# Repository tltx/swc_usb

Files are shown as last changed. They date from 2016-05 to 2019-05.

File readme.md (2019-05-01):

SWC USB Adapter
===============
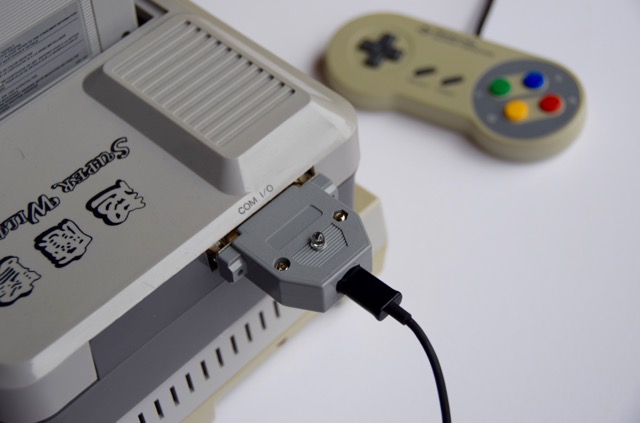
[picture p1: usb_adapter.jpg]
SWC USB Adapter


SWC USB Adapter is a peripheral for the Super Wild Card backup unit that makes it USB compatible.

Features
--------
* Connect a Super Wild Card via USB to a modern computer that does not have a parallel port.
* Compatible with most operating systems. The program is writen in Python and the adapter uses the USB CDC driver that is built into most modern operating systems.
* Transfer speed on par with parallel port transfer.
* No need for a thick parallel port cable.
* More convenient than floppies or a USB floppy emulator.
* The hardware parts are widely available and not too hard to assemble.
* Program auto detects the adapter, no need to specify the port.
* It is a open hardware and software project.

Usage example
-------------

To transfer a ROM file to the Super Wild Card:

`swc_usb.py send-rom --hirom <file>`

To fetch a SRAM dump:

`swc_usb.py fetch-sram <file>`

Questions and answers
----------------------
Q: Why not just use any USB to parallel adapter?

A: It won't work, almost all of them are for printers only, and if you find one that truly emulates a parallel port the latency of USB will make the transfers really slow.

Q: Do I need to surface mount solder and have a PCB manufactured?

A: You should be able to use any Atmega32u4 breakout board and solder wires from it to a male D-Sub 25 connector. That project hardware is basically the same thing but in a nicer form factor.

Q: How do I compile the firmware?

A: swc_usb.hex is a compiled firmware ready to be loaded onto the controller. If you want to compile it yourself, set up a AVR tool chain and run `make all` in the firmware directory.

Q: Does it have all the swc transfer features that Ucon64 has?

A: No, It can send ROM files, send SRAM, fetch SRAM. If there is interest in some other feature I might add it.

Q: Which variants of the Super Wild Card is supported?

A: I think it works on all but I have tested it on: Super Magicom (MS-3201), Super Wild Card (SMS3201), Super Wild Card DX (SWC3201)

Atmega32u4 pin mapping to the D-Sub
-----------------------------------

| Atmega32u4 | D-Sub |
|---|---|
| PB3 | 15 |
| PB4 | 13 |
| PB5 | 12 |
| PB6 | 10 |
| PB7 | 11 |
| PD0 | 2 |
| PD1 | 3 |
| PD2 | 4 |
| PD3 | 5 |
| PD4 | 6 |
| PD5 | 7 |
| PD6 | 8 |
| PD7 | 9 |
| PF4 | 1 |
| PF5 | 14 |
| PF6 | 16 |
| PF7 | 17 |
| GND | 25 |

Thanks
------
This project would probably not have been made without the awesome [LUFA](http://www.fourwalledcubicle.com/LUFA.php) library. [Ucon64](http://ucon64.sourceforge.net/) have been a great source of information on how to communicate with the SWC and a starting point for code.

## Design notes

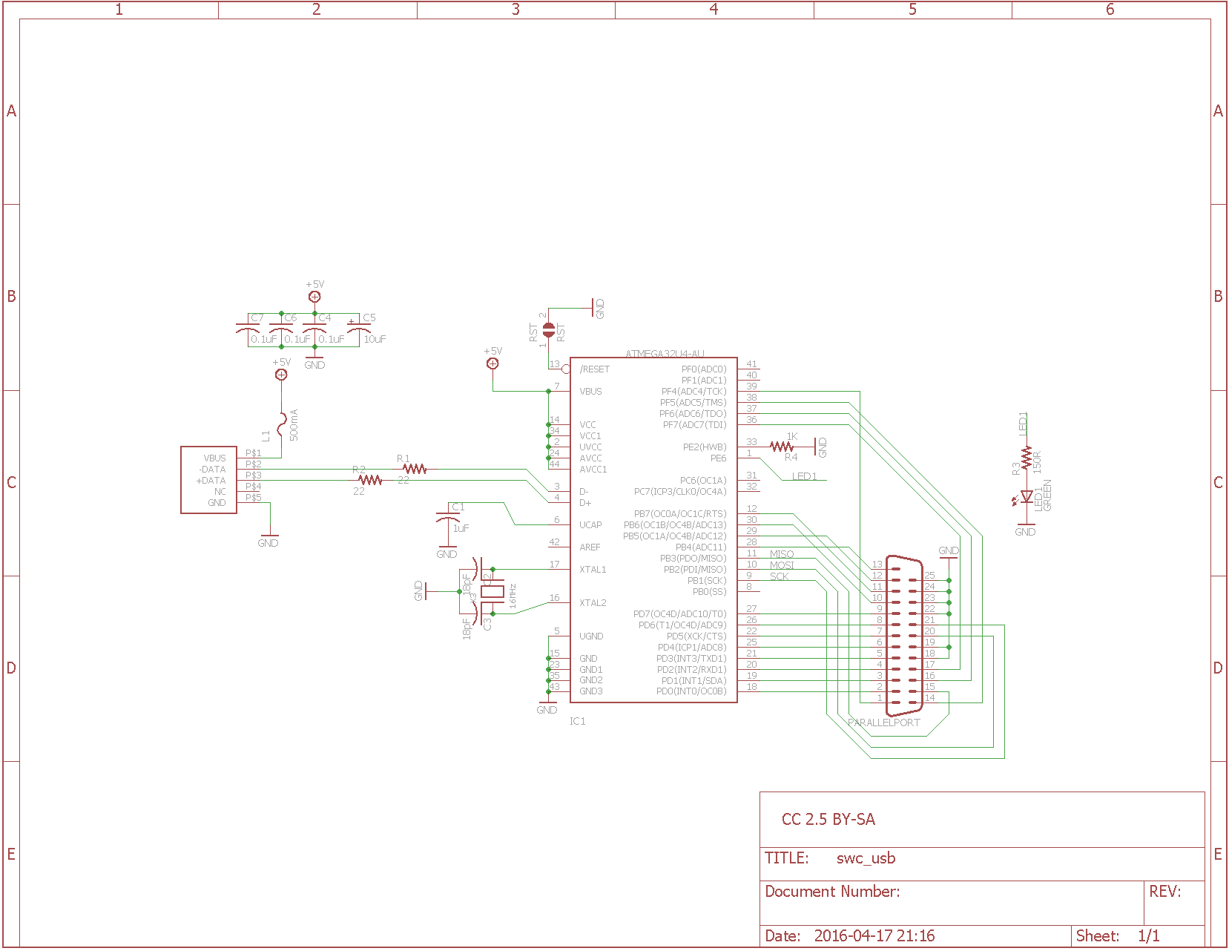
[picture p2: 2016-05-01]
pcb/swc_usb_schematic.png

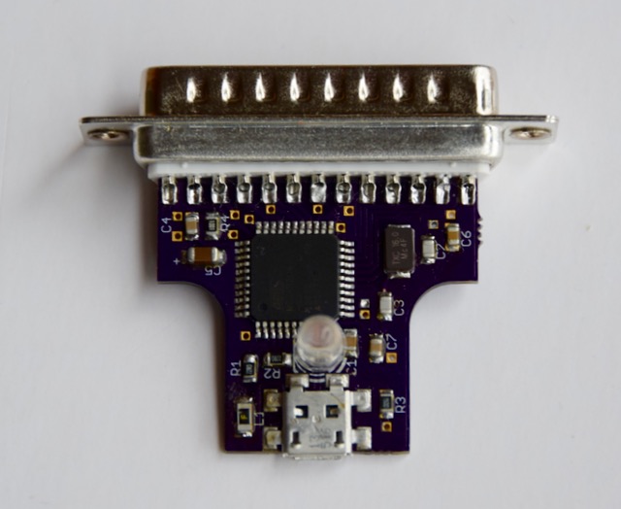
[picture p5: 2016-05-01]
pcb/usb_adapter_pcb.jpg

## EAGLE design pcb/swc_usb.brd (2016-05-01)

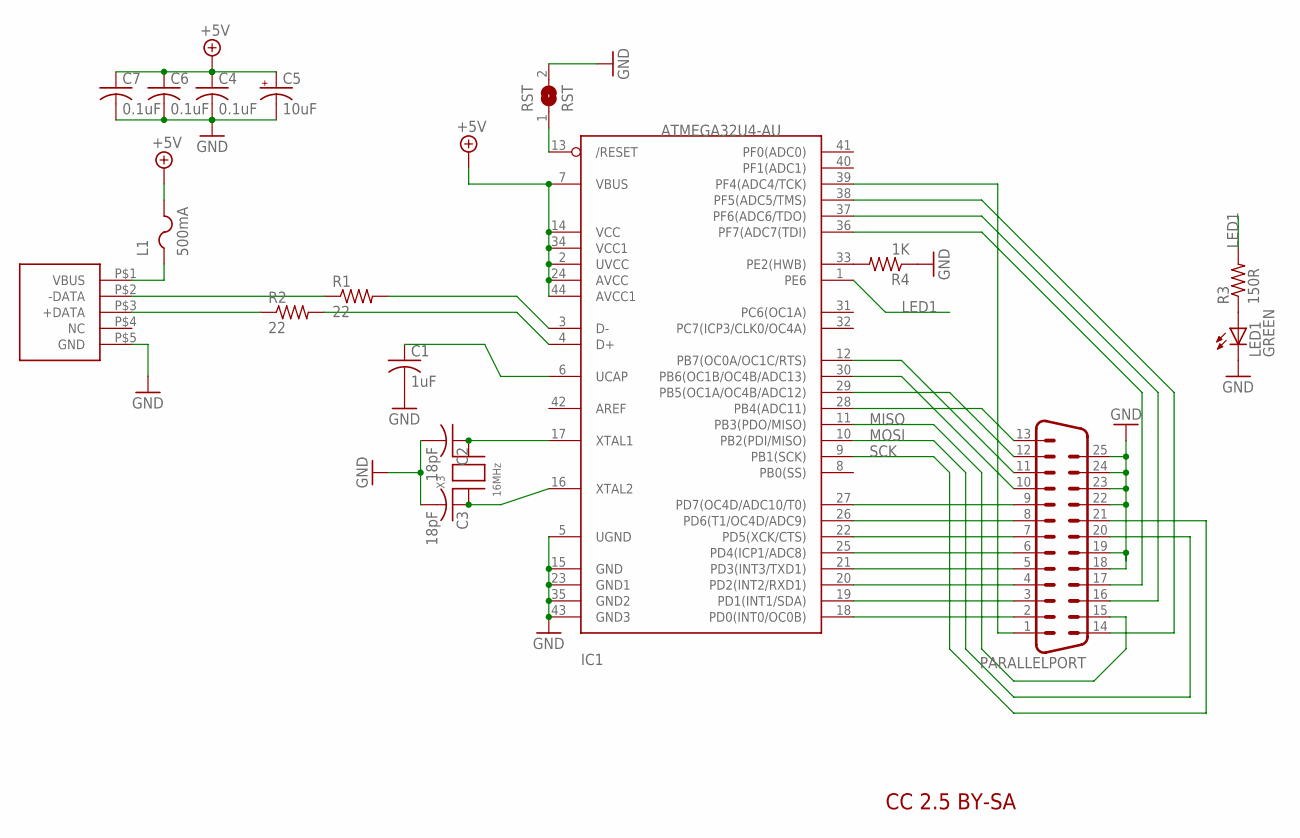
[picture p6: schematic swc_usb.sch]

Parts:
C1: 1uF; C0805K; MPN 0805B104K500CT
C2, C3: 18pF; C0805K; MPN 0805N180J500CT
C4, C6, C7: 0.1uF; C0805K; MPN 0805B104K500CT
C5: 10uF; A/3216-18R; MPN 1206B106K160CT
IC1: ATMEGA32U4-AU; TQFP44; MPN ATMEGA32U4-AU
L1: 500mA; R1206; MPN 1206L050YR.
LED1: GREEN; LED5MM; MPN SSL-LX5093XAC
PARALLELPORT: M25D; MPN SDB25PTD
R1, R2: 22; R0805; MPN WCR0805-22RFI
R3: 150R; R0805; MPN WCR0805-150RFI
R4: 1K; R0805; MPN RC0805FR-071KL
RST: RST; SJ
U$1: MICRO_USB_MID; MPN 47491-0001
X3: 16MHz; NX5032; MPN X1G0044510002 SG5032CAN 16 MHZ TJGA

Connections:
+5V: C4.1, C5.+, C6.1, C7.1, IC1.2 (UVCC), IC1.7 (VBUS), IC1.14 (VCC), IC1.24 (AVCC), IC1.34 (VCC1), IC1.44 (AVCC1), L1.2
GND: C1.2, C2.2, C3.2, C4.2, C5.-, C6.2, C7.2, IC1.5 (UGND), IC1.15 (GND), IC1.23 (GND1), IC1.35 (GND2), IC1.43 (GND3), LED1.K (C), PARALLELPORT.18, PARALLELPORT.19, PARALLELPORT.22, PARALLELPORT.23, PARALLELPORT.24, PARALLELPORT.25, R4.1, RST.2, U$1.P$5 (GND)
LED1: IC1.1 (PE6), R3.2
MISO: IC1.11 (PB3(PDO/MISO)), PARALLELPORT.15
MOSI: IC1.10 (PB2(PDI/MISO)), PARALLELPORT.20
unnamed: LED1.A, R3.1
unnamed: R2.1, U$1.P$3 (+DATA)
unnamed: IC1.3 (D-), R1.2
unnamed: IC1.4 (D+), R2.2
unnamed: R1.1, U$1.P$2 (-DATA)
unnamed: IC1.18 (PD0(INT0/OC0B)), PARALLELPORT.2
unnamed: IC1.19 (PD1(INT1/SDA)), PARALLELPORT.3
unnamed: C2.1, IC1.17 (XTAL1), X3.P$2
unnamed: C3.1, IC1.16 (XTAL2), X3.P$1
unnamed: C1.1, IC1.6 (UCAP)
unnamed: IC1.20 (PD2(INT2/RXD1)), PARALLELPORT.4
unnamed: IC1.21 (PD3(INT3/TXD1)), PARALLELPORT.5
unnamed: IC1.25 (PD4(ICP1/ADC8)), PARALLELPORT.6
unnamed: IC1.22 (PD5(XCK/CTS)), PARALLELPORT.7
unnamed: IC1.26 (PD6(T1/OC4D/ADC9)), PARALLELPORT.8
unnamed: IC1.27 (PD7(OC4D/ADC10/T0)), PARALLELPORT.9
unnamed: IC1.28 (PB4(ADC11)), PARALLELPORT.13
unnamed: IC1.29 (PB5(OC1A/OC4B/ADC12)), PARALLELPORT.12
unnamed: IC1.30 (PB6(OC1B/OC4B/ADC13)), PARALLELPORT.10
unnamed: IC1.12 (PB7(OC0A/OC1C/RTS)), PARALLELPORT.11
unnamed: IC1.39 (PF4(ADC4/TCK)), PARALLELPORT.1
unnamed: IC1.33 (PE2(HWB)), R4.2
unnamed: IC1.36 (PF7(ADC7(TDI)), PARALLELPORT.17
unnamed: IC1.37 (PF6(ADC6/TDO)), PARALLELPORT.16
unnamed: IC1.38 (PF5(ADC5/TMS)), PARALLELPORT.14
RST: IC1.13 (/RESET), RST.1
SCK: IC1.9 (PB1(SCK)), PARALLELPORT.21
VBUS: L1.1, U$1.P$1 (VBUS)

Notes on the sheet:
CC 2.5 BY-SA

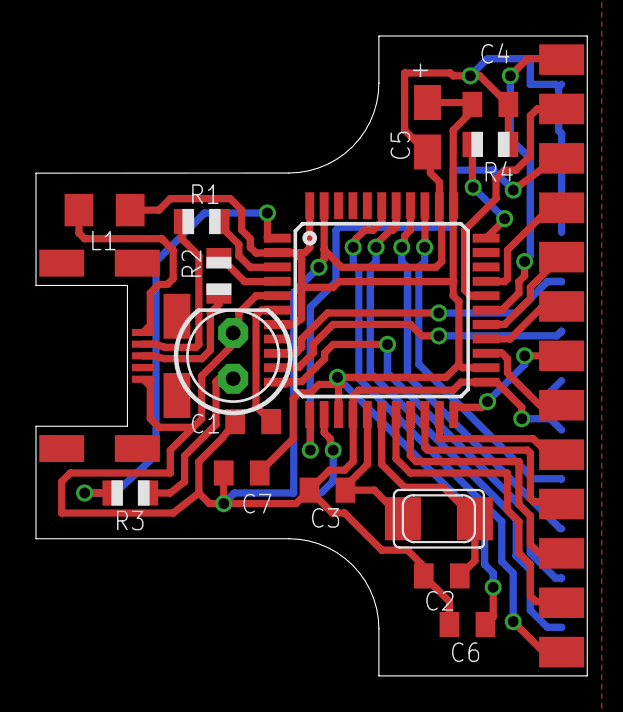
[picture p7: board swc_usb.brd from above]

Board: 2 copper layers, 30.6 x 35.5 mm, 18 parts (1 on the bottom side), 33 nets.

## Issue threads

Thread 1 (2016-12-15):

Can't flash hex file.

michaelpetri, 2016-12-15:
Hi,

first of all, really nice project! I'm looking forward to upgrade my swc!

I've bought this ATmega32u4 (http://www.ebay.de/itm/301951688967?_trksid=p2057872.m2749.l2649&ssPageName=STRK%3AMEBIDX%3AIT)

Now i'm trying to flash your hex file via avrdude on osx 10.11.6

first im not sure do i need to write into the flashmemory or the eeprom?

anyway i tried to verify both with the following two commands, both fail while verification:

**Flashmemory:**
```avrdude -p m32u4 -P /dev/cu.usbmodem1421 -c avr109 -U flash:v:$(pwd)/Desktop/swc_usb.hex```

**Output:**
```
Connecting to programmer: .
Found programmer: Id = "CATERIN"; type = S
    Software Version = 1.0; No Hardware Version given.
Programmer supports auto addr increment.
Programmer supports buffered memory access with buffersize=128 bytes.

Programmer supports the following devices:
    Device code: 0x44

avrdude: AVR device initialized and ready to accept instructions

Reading | ################################################## | 100% 0.00s

avrdude: Device signature = 0x1e9587 (probably m32u4)
avrdude: verifying flash memory against /Users/michaelpetri/Desktop/swc_usb.hex:
avrdude: load data flash data from input file /Users/michaelpetri/Desktop/swc_usb.hex:
avrdude: input file /Users/michaelpetri/Desktop/swc_usb.hex auto detected as Intel Hex
avrdude: input file /Users/michaelpetri/Desktop/swc_usb.hex contains 6764 bytes
avrdude: reading on-chip flash data:

Reading | ################################################## | 100% 0.07s

avrdude: verifying ...
avrdude: verification error, first mismatch at byte 0x0000
         0x0c != 0x9b
avrdude: verification error; content mismatch

avrdude: safemode: Fuses OK (E:CB, H:D8, L:FF)

avrdude done.  Thank you.
```

**Eeprom:**
```avrdude -p m32u4 -P /dev/cu.usbmodem1421 -c avr109 -U eeprom:v:$(pwd)/Desktop/swc_usb.hex```

**Output:**
```
Connecting to programmer: .
Found programmer: Id = "CATERIN"; type = S
    Software Version = 1.0; No Hardware Version given.
Programmer supports auto addr increment.
Programmer supports buffered memory access with buffersize=128 bytes.

Programmer supports the following devices:
    Device code: 0x44

avrdude: AVR device initialized and ready to accept instructions

Reading | ################################################## | 100% 0.00s

avrdude: Device signature = 0x1e9587 (probably m32u4)
avrdude: verifying eeprom memory against /Users/michaelpetri/Desktop/swc_usb.hex:
avrdude: load data eeprom data from input file /Users/michaelpetri/Desktop/swc_usb.hex:
avrdude: input file /Users/michaelpetri/Desktop/swc_usb.hex auto detected as Intel Hex
avrdude: ERROR: address 0x0410 out of range at line 65 of /Users/michaelpetri/Desktop/swc_usb.hex
avrdude: read from file '/Users/michaelpetri/Desktop/swc_usb.hex' failed

avrdude: safemode: Fuses OK (E:CB, H:D8, L:FF)

avrdude done.  Thank you.
```

Hope you can help me, if you need more details let me know!

Thanks in advance
Michael

tltx, 2016-12-15:
Hi, nice to have someone trying out the project!

You should write to flash, use `-U flash:w:` to write. `-U flash:v:` is just verifying an extra time, you don't need to do that and if you haven't written the firmware first you are going to get a diff like you did.

This is the command I use:
`avrdude -c avr109 -p m32u4 -P /dev/tty.usbmodem411 -v -U flash:w:swc_usb.hex:i`

The board you are using seems to be a clone of [SparkFun Pro Micro](https://www.sparkfun.com/products/12640) and it does not have all the pins needed exposed on it.

PB7 och PD6 is marked as "Not used" in the schematics and PD5 is hooked up to a LED for example.

I recommend the [Teensy 2.0](https://www.pjrc.com/store/teensy.html), I haven't tried it myself but as far as I can see it has got everything you ned and it's small and I have heard good things about it.

michaelpetri, 2016-12-17:
Hi,

thanks for your fast response and feedback. Can you confirm this pcb should work?

http://www.ebay.de/itm/272356895154

Thanks
Michael

michaelpetri, 2016-12-18:
Sry just read you comment again and updated the product link.

tltx, 2016-12-18:
Hi, no the Teensy++ 2.0 has got another controller, maybe you could recompile for it. Look for a board with the ATMEGA32U4. [This looks like one](https://www.amazon.de/dp/B01N74RIKX/ref=sr_1_1?ie=UTF8&qid=1482098779&sr=8-1&keywords=teensy+2.0) (I don't speak German, so I'm not sure). The [Atmega32u4 Breakout Board](https://www.amazon.de/Adafruit-Atmega32u4-Breakout-Board/dp/B008AS3XHQ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) looks really nice to, it has got all the pins marked out on the board with the right names.

Closed 2017-01-25.

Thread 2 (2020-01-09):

Hi Tore

Mclaneinc, 2020-01-09:
Not ann issue but a bit of help needed re the Wildcard. I'm going to do the initial way you made it with no custom PCB but I presume you have to flash the ATMEGA32U4 with that hex, I've never done this before, can you give me a bit of help. Soldering is all fine, just the flashing and possible any other software I'm going to need?

Sorry to trouble you..

Mclaneinc, 2020-01-10:
Ignore...Explained in other issue..

Closed 2020-01-10.

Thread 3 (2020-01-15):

Can't install the hex or any drivers.

Mclaneinc, 2020-01-15:
Hi there, please try to excuse the lack of knowledge, I don't use python and never used one of these boards

No drivers came with the board

https://www.ebay.co.uk/itm/352722795632

I plug the board on to Windows 7  and I presume I press the button to stop the flashing but but using the suggested line for avrdude from your posts on here yields a cannot find \dev\usbmodem411 error.

Any help would be appreciated, the soldering I can do...

tltx, 2020-01-15:
Hi
I think you can leave out -P /dev... or use -P usb or -P COM1

Best regards

Tore

ons 15 jan. 2020 kl. 19:41 skrev Mclaneinc <notifications@github.com>:

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

Mclaneinc, 2020-01-15:
Hi Tore, thanks for the reply..

I've tried those and it complains of not finding a file called -v which is the next command line switch. I'm sure this is all down to some sort of Python serial port but my knowledge of python is very little. I managed to get pip to install pyserial and click but after that I have no idea how to use or make them work. In device manager I have no com port listed so presume its created by python??

As you can see that I'm quite lost, the soldering ok for me but I can't even get the hex file on the board :)

All I have is the board, a mini usb cable and plugged it in to my windows machine, it was flashing a lot so I pressed the switch, not sure if that was the right thing to do?

Paul.

tltx, 2020-01-15:
You should be able to follow this instructions
https://www.pjrc.com/teensy/loader_win10.html

ons 15 jan. 2020 kl. 21:27 skrev Mclaneinc <notifications@github.com>:

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

Mclaneinc, 2020-01-16:
Ah thank you...Just used it and seems to have worked...Brilliant...

Now to build the board and use the wildcard again after all these years..

Thank you so much Tore...

Mclaneinc, 2020-01-22:
Well had to wait for a couple of parts but its all soldered up and WORKING...

I hate python tho :)

Thank you Tore for making my old wild card have a second use..

tltx, 2020-01-23:
Just a tip. Remove the NiCd battery from the wild card and clean up the PCB, it's probably nasty. I replaced my battery with a super cap, that seems to work well for me.

Mclaneinc, 2020-01-23:
Will do, must admit I'd did look but saw no leakage but it was a brief glance...

Thanks again for a wonderful little mod...

Paul.

Closed 2020-01-23.

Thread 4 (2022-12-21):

SWC usb fully assembled

danko79, 2022-12-21:
Hi, sorry for this issue opened, i need a fully assembled swc usb, do you have for sale?

Closed 2024-01-15.

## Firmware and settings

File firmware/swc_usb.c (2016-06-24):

#include "swc_usb.h"

USB_ClassInfo_CDC_Device_t VirtualSerial_CDC_Interface =
    {
        .Config =
            {
                .ControlInterfaceNumber   = INTERFACE_ID_CDC_CCI,
                .DataINEndpoint           =
                    {
                        .Address          = CDC_TX_EPADDR,
                        .Size             = CDC_TXRX_EPSIZE,
                        .Banks            = 1,
                    },
                .DataOUTEndpoint =
                    {
                        .Address          = CDC_RX_EPADDR,
                        .Size             = CDC_TXRX_EPSIZE,
                        .Banks            = 1,
                    },
                .NotificationEndpoint =
                    {
                        .Address          = CDC_NOTIFICATION_EPADDR,
                        .Size             = CDC_NOTIFICATION_EPSIZE,
                        .Banks            = 1,
                    },
            },
    };

static FILE USBSerialStream;

bool timeout = false;
#define COMMAND_LEN 11

int main(void) {
    setup_hardware();

    /* Create a regular character stream for the interface so that it can be used with the stdio.h functions */
    CDC_Device_CreateStream(&VirtualSerial_CDC_Interface, &USBSerialStream);

    GlobalInterruptEnable();

    uint8_t raw_command[COMMAND_LEN];
    uint8_t arguments[3];

    for (; ;) {
        cdc_device_receive_bytes(raw_command, COMMAND_LEN);
        raw_command[COMMAND_LEN-1] = '\0';
        char *command = (char *) raw_command;

        activate_ports();
        if (strcmp(command, "WRITE ROM") == 0) {
            cdc_device_receive_bytes(arguments, 3);
            uint16_t total_blocks = (arguments[0] << 8) | arguments[1];
            uint8_t emu_mode_select = arguments[2];
            write_rom(total_blocks, emu_mode_select);
        }
        else if (strcmp(command, "READ SRAM") == 0) {
            read_sram();
        }
        else if (strcmp(command, "WRITE SRAM") == 0) {
            cdc_device_receive_bytes(arguments, 2);
            uint16_t total_bytes = (arguments[0] << 8) | arguments[1];
            write_sram(total_bytes);
        }
        else {
            send_feedback("UNKNOWN COMMAND\n");
        }
        deactivate_ports();
        if (timeout) {
            send_feedback("TIMEOUT\n");
            timeout = false;
        }
        while (CDC_Device_ReceiveByte(&VirtualSerial_CDC_Interface) > -1) {
            USB_tasks();
        }
        USB_tasks();
    }
}

void cdc_device_receive_bytes(uint8_t *buffer, uint8_t length) {
    for (uint8_t bytes_received = 0; length > bytes_received;) {
        int16_t received_byte = CDC_Device_ReceiveByte(&VirtualSerial_CDC_Interface);
        if (received_byte >= 0) {
            buffer[bytes_received++] = (uint8_t) received_byte;
        }
        USB_tasks();
    }
}

void setup_hardware(void) {
    /* Disable watchdog if enabled by bootloader/fuses */
    MCUSR &= ~(1 << WDRF);
    wdt_disable();

    /* Disable JTAG to free up PORTF pins */
    JTAG_DISABLE();

    /* Disable clock division */
    clock_prescale_set(clock_div_1);

    /* Hardware Initialization */
    USB_Init();
}

void activate_ports(void) {
    /* Set port D as output for Data */
    PORTD = 0x00;
    DDRD = 0xFF;

    /* Set port B as input for Status */
    PORTB = 0xFF; //enable all pull-ups
    DDRB = 0x00;

    /* Set port F as output for Control */
    PORTF = 0x00;
    DDRF = 0xF0;

    /* Set LED */
    PORTE = 0x40;
    DDRE = 0x40;
}

void deactivate_ports(void) {
    /* Set port D to input */
    PORTD = 0x00;
    DDRD = 0x00;

    /* Set port B to input */
    PORTB = 0x00; //disable all pull-ups
    DDRB = 0x00;

    /* Set port F to input */
    PORTF = 0x00;
    DDRF = 0x00;

    /* Set LED */
    PORTE = 0x00;
    DDRE = 0x00;
}

void send_feedback(char const *fmt, ...) {
    va_list argptr;
    va_start(argptr, fmt);
    vfprintf(&USBSerialStream, fmt, argptr);
    va_end(argptr);
    CDC_Device_Flush(&VirtualSerial_CDC_Interface);
}

void USB_tasks(void) {
    CDC_Device_USBTask(&VirtualSerial_CDC_Interface);
    USB_USBTask();
}

/** Event handler for the library USB Configuration Changed event. */
void EVENT_USB_Device_ConfigurationChanged(void) {
    CDC_Device_ConfigureEndpoints(&VirtualSerial_CDC_Interface);
}

/** Event handler for the library USB Control Request reception event. */
void EVENT_USB_Device_ControlRequest(void) {
    CDC_Device_ProcessControlRequest(&VirtualSerial_CDC_Interface);
}

/* SWC stuff */
#define PARPORT_INPUT_MASK 0x78
#define PARPORT_IBUSY 0x80
#define PARPORT_STROBE 0x1
#define POLL_MAX 65534
#define BLOCK_SIZE 8192                // don't change, only 8192 works!

void write_data(uint8_t byte) {
    /* Port D
     *  dsub25		register
     *  2 to 9		D0+ to D7+
     */
    PORTD = byte;
}

void write_control(uint8_t byte) {
    /* Port F 4-7
     *  dsub25  name    register (- means inverted signal high=0)
     * 	17      Select  C3-
     * 	16      Init    C2+
     * 	14      AutoFd  C1-
     * 	 1      Strobe  C0-
     */
    PORTF = (byte ^ 0b00001011) << 4;
}

uint8_t read_control(void) {
    //Port F 4-7
    return (PINF >> 4) ^ 0b00001011;
}

uint8_t read_status(void) {
    /* Port B
     *  dsub25  name       register (- means inverted signal high=0)
     *	11      Busy       S7-
     *	10      Ack        S6+
     *	12      PaperEnd   S5+
     *	13      SelectIn   S4+
     *	15      Error      S3+
     */
    return PINB ^ PARPORT_IBUSY;
}

void wait_busy_bit(bool bit, uint8_t poll_min) {
    bool busy_bit = false;
    uint16_t poll_count = 0;

    if (timeout) {
        return;
    }

    do {
        busy_bit = (bool) (read_status() & PARPORT_IBUSY);
        ++poll_count;
    } while (poll_count < poll_min || (busy_bit != bit && poll_count < POLL_MAX));

    if (busy_bit != bit) {
        timeout = true;
    }
}

void flip_led(void) {
    PORTE = PORTE ^ 0x40;
}

void invert_strobe(void) {
    write_control(read_control() ^ PARPORT_STROBE);
    flip_led();
}

void send_byte(uint8_t byte) {
    wait_busy_bit(1, 0);
    write_data(byte);
    invert_strobe();
    wait_busy_bit(1, 0); // necessary if followed by receive_byte()
}

void send_command(uint8_t command_code, uint16_t address, uint16_t length) {
    send_byte(0xD5);
    send_byte(0xAA);
    send_byte(0x96);
    send_byte(command_code);
    send_byte(address);
    send_byte(address >> 8);
    send_byte(length);
    send_byte(length >> 8);
    send_byte(0x81 ^ command_code ^ address ^ (address >> 8) ^ length ^ (length >> 8)); // checksum
}

void send_command0(uint16_t address, uint8_t byte) {
    /* command 0 for 1 byte */
    send_command(0, address, 1);
    send_byte(byte);
    send_byte(0x81 ^ byte);
}

void send_block(uint16_t address, uint16_t block_size) {
    uint8_t checksum = 0x81;

    send_command(0, address, block_size);
    for (uint16_t n = 0; n < block_size;) {
        USB_tasks();
        uint16_t number_of_bytes_ready = CDC_Device_BytesReceived(&VirtualSerial_CDC_Interface);
        for (uint16_t i = 0; i < number_of_bytes_ready; ++i) {
            uint8_t byte = (uint8_t) CDC_Device_ReceiveByte(&VirtualSerial_CDC_Interface);
            send_byte(byte);
            checksum ^= byte;
            ++n;
        }
    }
    send_byte(checksum);
}

void write_rom(uint16_t total_blocks, uint8_t emu_mode_select) {
    uint16_t block = 0;
    uint16_t address = 0x200;

    for (; block < total_blocks; ++block) {
        send_command0(0xC010, block >> 9);
        send_command(5, address, 0);
        send_block(0x8000, BLOCK_SIZE);
        ++address;
        if (timeout) {
            return;
        }
    }

    if (block > 0x200)
        send_command0(0xC010, 1);

    send_command(5, 0, 0);
    send_command(6, 5 | (total_blocks << 8), total_blocks >> 8); // bytes: 6, 5, #8 K L, #8 K H, 0
    send_command(6, 1 | (emu_mode_select << 8), 0); // last arg = 1 enables RTS mode, 0 disables it

    send_feedback("OK\n");
}

uint8_t receive_byte(void) {
    wait_busy_bit(0, 3);
    uint8_t byte = (read_status() & PARPORT_INPUT_MASK) >> 3; // receive low nibble
    invert_strobe();
    wait_busy_bit(0, 3);
    byte |= (read_status() & PARPORT_INPUT_MASK) << 1; // receive high nibble
    invert_strobe();
    return byte;
}

bool receive_block(uint16_t address, uint16_t len) {
    uint8_t checksum = 0x81;
    send_command(1, address, len);
    for (uint16_t n = 0; n < len; ++n) {
        uint8_t byte = receive_byte();
        CDC_Device_SendData(&VirtualSerial_CDC_Interface, &byte, 1);
        checksum ^= byte;
    }
    return checksum != receive_byte();  //Compare calculated checksum with received checksum
}

void read_sram(void) {
    send_command(5, 0, 0);
    send_command0(0xE00D, 0);
    send_command0(0xC008, 0);

    uint8_t blocks_left = 4;  // SRAM is 4*8 KiB
    uint16_t address = 0x100;
    uint8_t error_count = 0;
    while (blocks_left > 0) {
        send_command(5, address, 0);
        error_count += receive_block(0x2000, BLOCK_SIZE);
        _delay_ms(50);
        --blocks_left;
        ++address;
        if (timeout) {
            return;
        }
    }
    CDC_Device_Flush(&VirtualSerial_CDC_Interface);
    if (error_count) {
        send_feedback("*#*#*ERR%s\n", error_count);
    }
    else {
        send_feedback("*#*#*#*OK\n");
    }
}

void write_sram(uint16_t total_bytes) {
    send_command(5, 0, 0);
    send_command0(0xE00D, 0);
    send_command0(0xC008, 0);

    uint16_t address = 0x100;
    uint16_t last_block_size = total_bytes % BLOCK_SIZE;
    uint8_t blocks = total_bytes / BLOCK_SIZE;
    if (last_block_size) {
        ++blocks;
    }
    uint16_t block_size = BLOCK_SIZE;
    for (uint8_t block = 0; block < blocks; ++block) {
        if (last_block_size && block == (blocks - 1)) {
            block_size = last_block_size;
        }
        send_command(5, address, 0);
        send_block(0x2000, block_size);
        ++address;
        if (timeout) {
            return;
        }
    }
    send_feedback("OK\n");
}

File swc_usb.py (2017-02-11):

#!/usr/bin/env python
from collections import namedtuple
from io import BytesIO
from time import sleep, time

import serial
import click
from serial.tools import list_ports
from struct import pack, unpack_from

BLOCK_SIZE = 8192
SWC_HEADER_SIZE = 512
LO_ROM = 'lo_rom'
HI_ROM = 'hi_rom'


def detect_com_port():
    for port in list_ports.comports():
        if port.vid == 0x03EB and port.pid == 0x2044:
            return port.device
    raise click.ClickException('Could not auto detect the SWC USB adapter.')


def send(com_port, command, data):
    start_time = time()
    with serial.Serial(com_port, timeout=0) as ser:
        ser.write(command)
        feedback = b''
        with click.progressbar(range(0, len(data), BLOCK_SIZE), label='Sending') as block_offsets:
            for block_start in block_offsets:
                ser.write(data[block_start:block_start + BLOCK_SIZE])
                feedback = check_feedback(ser, feedback)
            ser.flush()
            check_feedback(ser, feedback, wait_ok=30)
    click.echo(click.style('Transfer complete in {0:.2f} seconds.'.format(time() - start_time), fg='green'))


def check_feedback(ser, feedback, wait_ok=0):
    while True:
        feedback += ser.read(size=100)
        if b'OK' in feedback:
            break
        elif b'TIMEOUT' in feedback:
            raise click.ClickException('Transfer timeout, is the USB adapter connected to the Super Wild Card? Power cycle the SNES might fix this.')
        elif b'UNKNOWN COMMAND' in feedback:
            raise click.ClickException('Transfer failed!')
        if wait_ok > 0:
            wait_ok -= 1
            if wait_ok == 0:
                raise click.ClickException('Transfer failed!')
            sleep(0.1)
        else:
            break
    return feedback


@click.group()
@click.option('--com-port', default=detect_com_port, help='The USB CDC virtual serial port of the adapter. Only needed if auto detect does not work.')
@click.pass_context
def main(ctx, com_port):
    """Program that communicates with the Super Wild Card via a custom USB adapter."""
    ctx.obj['com_port'] = com_port


@main.command(name='send-rom')
@click.option('--hirom/--lorom', default=None, help="Run the ROM in HiROM or LoROM mode.")
@click.option('--sram-size',  type=click.Choice(['0', '16', '64']), default=None, help="Set SRAM size for ROM in Kibit e.g. --sram-size=64")
@click.argument('rom_file', type=click.File('rb'))
@click.pass_obj
def send_rom(ctx, hirom, sram_size, rom_file):
    """Send a ROM file to the Super Wild Card."""
    rom = rom_file.read()
    _, rom = separate_swc_header(rom)
    rom_type, snes_header_sram_size = determine_rom_type_and_sram_size(rom)
    if hirom is not None:
        rom_type = HI_ROM if hirom else LO_ROM
    if sram_size:
        emu_byte_sram_size = (int(sram_size) * 1024) // 8
    else:
        emu_byte_sram_size = snes_header_sram_size
    emu_byte = emulation_mode_select(rom_type=rom_type, sram_size=emu_byte_sram_size)
    blocks = len(rom) // BLOCK_SIZE
    command = pack('>10sxHB', b'WRITE ROM', blocks, emu_byte)
    send(ctx['com_port'], command, rom)


@main.command(name='send-sram')
@click.argument('sram_file', type=click.File('rb'))
@click.pass_obj
def send_sram(ctx, sram_file):
    """Send a SRAM file to the Super Wild Card."""
    sram = sram_file.read()
    _, sram = separate_swc_header(sram)
    total_bytes = len(sram)
    command = pack('>10sxH', b'WRITE SRAM', total_bytes)
    send(ctx['com_port'], command, sram)


@main.command(name='fetch-sram')
@click.argument('sram_file', type=click.File('wb'))
@click.pass_obj
def fetch_sram(ctx, sram_file):
    """Fetch a SRAM dump from the Super Wild Card."""
    with serial.Serial(ctx['com_port'], timeout=3) as ser:
        start_time = time()
        ser.write(pack('>10sx', b'READ SRAM'))
        sram = BytesIO()
        with click.progressbar(range(0, BLOCK_SIZE * 4), label='Receiving') as all_bytes:
            for _ in all_bytes:
                byte = ser.read(size=1)
                if byte == b'':
                    raise click.ClickException('Transfer timeout.')
                sram.write(byte)
        trail = ser.read(size=9)
        if trail != b'*#*#*#*OK':
            raise click.ClickException('Transfer failed! ({})'.format(trail))
        sram_file.write(sram.getbuffer())
        click.echo(click.style('Transfer complete in {0:.2f} seconds.'.format(time() - start_time), fg='green'))


def emulation_mode_select(rom_type, sram_size):
    emu_byte = 0x00
    if rom_type == HI_ROM:
        emu_byte |= 0x30

    bits_by_sram_size = {
        8192: 0x04,
        2048: 0x08,
        0: 0x0C,
    }

    emu_byte |= bits_by_sram_size.get(sram_size, 0x00)
    return emu_byte


def separate_swc_header(rom):
    swc_header = namedtuple('SwcHeader', ('emulation', 'id1', 'id2', 'type'))(*unpack_from('2xB5x3B', rom))
    if (
        swc_header.id1 == 0xAA and
        swc_header.id2 == 0xBB and
        swc_header.type in (0x04, 0x05) and
        len(rom) % BLOCK_SIZE == SWC_HEADER_SIZE
    ):
        return swc_header, rom[SWC_HEADER_SIZE:]
    else:
        return None, rom


def determine_rom_type_and_sram_size(rom):
    lo_header = parse_header(rom[0x7FC0:0x7FFF])
    hi_header = parse_header(rom[0xFFC0:0xFFFF])
    rom_size = len(rom)
    lo_rom_rank = rank_header(header=lo_header, expected_rom_type=LO_ROM, rom_size=rom_size)
    hi_rom_rank = rank_header(header=hi_header, expected_rom_type=HI_ROM, rom_size=rom_size)

    if hi_rom_rank > lo_rom_rank:
        return HI_ROM, snes_header_size_in_bytes(hi_header.sram_size)
    else:
        return LO_ROM, snes_header_size_in_bytes(lo_header.sram_size)


def rank_header(header, expected_rom_type, rom_size):
    rank = 0
    markup_bytes = {
        LO_ROM: [0x20, 0x30, 0x32],
        HI_ROM: [0x21, 0x31, 0x35],
    }
    sram_sizes = [2048, 4096, 8192]

    if header.rom_makeup_byte in markup_bytes[expected_rom_type]:
        rank += 1

    if all(0x1F < byte < 0x7F for byte in header.game_title):
        rank += 1

    if snes_header_size_in_bytes(header.rom_size) == rom_size:
        rank += 1

    if snes_header_size_in_bytes(header.sram_size) in sram_sizes:
        rank += 1

    if header.country < 14:
        rank += 1

    if header.checksum ^ header.checksum_complement == 0xFFFF:
        rank += 1
    return rank


def snes_header_size_in_bytes(size_byte):
    if size_byte == 0:
        return 0
    else:
        return 0x400 << size_byte


def parse_header(header_bytes):
    header = namedtuple(
        'SnesHeader',
        (
            'game_title',
            'rom_makeup_byte',
            'rom_type',
            'rom_size',
            'sram_size',
            'country',
            'license',
            'version',
            'checksum_complement',
            'checksum',
        )
    )(*unpack_from('21s7B2H', header_bytes[:32]))
    return header


if __name__ == '__main__':
    main(obj={})
